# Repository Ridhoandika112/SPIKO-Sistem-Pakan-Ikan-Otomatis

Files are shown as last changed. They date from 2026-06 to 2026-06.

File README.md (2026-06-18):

#  Sistem Pakan Ikan Otomatis Di Aquarium Berbasis IoT


# Deskripsi Proyek
Proyek ini memanfaatkan mikrokontroler Arduino Mega (ATMega2560) sebagai platform utama, yang terintegrasi dengan beberapa sensor dan aktuator, yaitu sensor suhu air DS18B20, sensor pH, motor servo sebagai mekanisme pembuka pakan, serta modul RTC DS3231 untuk pengaturan dan penjadwalan waktu yang presisi. Sistem ini bertujuan untuk mengotomatisasi proses pemberian pakan ikan sesuai jadwal yang telah ditentukan. Data parameter kualitas air (suhu dan pH) akan dikirimkan secara kontinu ke sebuah dashboard web yang dapat diakses dari jarak jauh melalui internet. Selain fitur otomatisasi, sistem juga menyediakan fasilitas kontrol manual melalui aplikasi mobile atau web, sehingga pengguna tetap dapat mengintervensi pemberian pakan secara langsung sesuai kebutuhan.

---

# Tujuan Proyek
Membangun sistem otomatisasi pemberian pakan ikan berbasis mikrokontroler Arduino Mega yang dapat bekerja secara terjadwal, memantau kualitas air secara real-time, serta memungkinkan pengendalian dan pemantauan jarak jauh melalui dashboard web.

---
## Support By

> * Dosen Pengampu: Akhmad Hendriawan ST., MT. (NIP. 197501272002121003)
> * Mata Kuliah: Mikrokontroller
> * Program Studi: D4 Teknik Elektronika 
> * Politeknik Elektronika Negeri Surabaya

#  Anggota Tim


| NRP | Nama | Jobdesk | Akun |
|-----|---|---|---|
| 2124600031 | Aidan Pasha Rabani | Project Manager | [Aidan031](https://github.com/Aidan031) |
| 2124600034 | M Arya Cendekia S| Hardware Specialist | [maryacs212434](https://github.com/maryacs212434) |
| 2124600058 | M Reihan Maulana | Programmer | [reiihaaannn](https://github.com/reiihaaannn) |
| 2124600043 | Sabrina Keisha Maharani | UI/UX Designer | [sabrinakeisha](https://github.com/sabrinakeisha) |
| 2124600051 | M Ridho Andika | 3D Designer | [Ridhoandika112](https://github.com/Ridhoandika112) |
| 2124600035 | Setyo Wahyu Nur F | Hardware Specialist |[bopengfirmansyah-sketch](https://github.com/bopengfirmansyah-sketch)|

---

### Fitur Utama

| Fitur | Kegunaan |
| :---: | :---: |
|**IoT Web Dashboard** | Antarmuka pengguna responsif untuk pemantauan kualitas air dan status perangkat secara *real-time*. |
|**Penjadwalan Presisi** | Pemberian pakan otomatis yang diatur secara presisi menggunakan modul RTC DS3231. |
|**Sensor Suhu DS18B20** | Pembacaan suhu air kolam secara akurat (protokol *One-Wire*) untuk memantau kelayakan habitat. |
|**Sensor pH Analog** | Deteksi tingkat keasaman atau kebasaan air secara berkesinambungan untuk mencegah anomali. |
|**Dual Control Mode** | Mendukung eksekusi pemberian pakan secara otomatis sesuai jadwal maupun *override* kontrol manual. |
|**Arduino Mega 2560** | Pusat komputasi sistem yang tangguh dengan kapasitas I/O berlimpah untuk kelancaran multi-sensor. |
|**Aktuator Presisi** | Menggunakan Motor Servo untuk mekanisme katup pakan dengan pengaturan porsi (Kecil, Sedang, Besar). |

---

### Daftar Komponen & Spesifikasi Perangkat Keras

| Komponen | Spesifikasi / Konfigurasi Pin | Fungsi Utama pada Sistem |
| :---: | :---: | :---: |
|**Arduino Mega 2560** | ATmega2560, 5V, 16 MHz | Mikrokontroler utama sebagai pusat pemrosesan logika kontrol, pembacaan data sensor, dan eksekusi aktuator. |
| **Motor Servo** | *PWM Output* (Pin Digital 9) | Bertindak sebagai mekanik pembuka dan penutup katup wadah pakan sesuai porsi/durasi yang diinstruksikan. |
|**Modul RTC (Real-Time Clock)** | DS1307 / DS3231 (I²C: SDA Pin 20, SCL Pin 21) | Menyediakan data waktu nyata (jam, kalender) yang presisi agar jadwal pakan otomatis tidak terpengaruh saat sistem *restart*. |
| **Sensor Suhu DS18B20** | *One-Wire Digital* (Pin Digital 10) | Memantau perubahan suhu air kolam secara presisi dan mengirimkan data secara digital ke mikrokontroler. |
|**Sensor pH Air** | *Analog Input* (Pin Analog A0) | Mendeteksi tingkat keasaman/kebasaan air. *(Catatan: Pada diagram simulasi, modul ini diwakili oleh komponen Potensiometer)*. |

---

## PPT ##
<a href="https://canva.link/strf7c127qnlvye" target="_blank">
  
</a>

## Blok Diagram ##


## 3D DESIGN ##
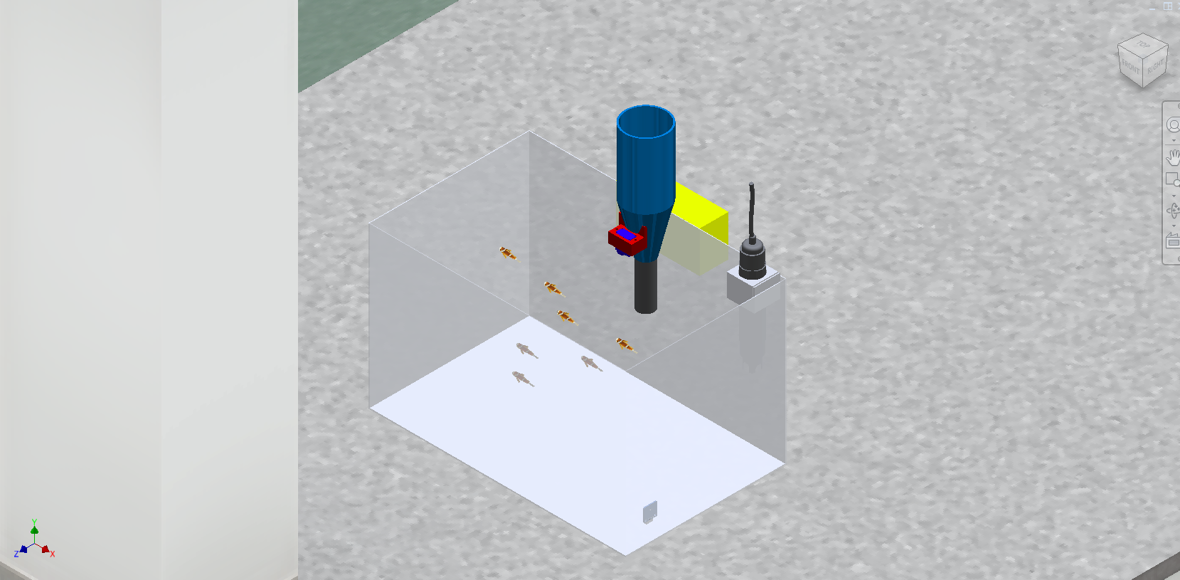
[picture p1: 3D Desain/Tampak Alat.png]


## Schematic ##
Schematic Hardware

## Board Layout ##
Board Layout

## 3D DESIGN PCB ##
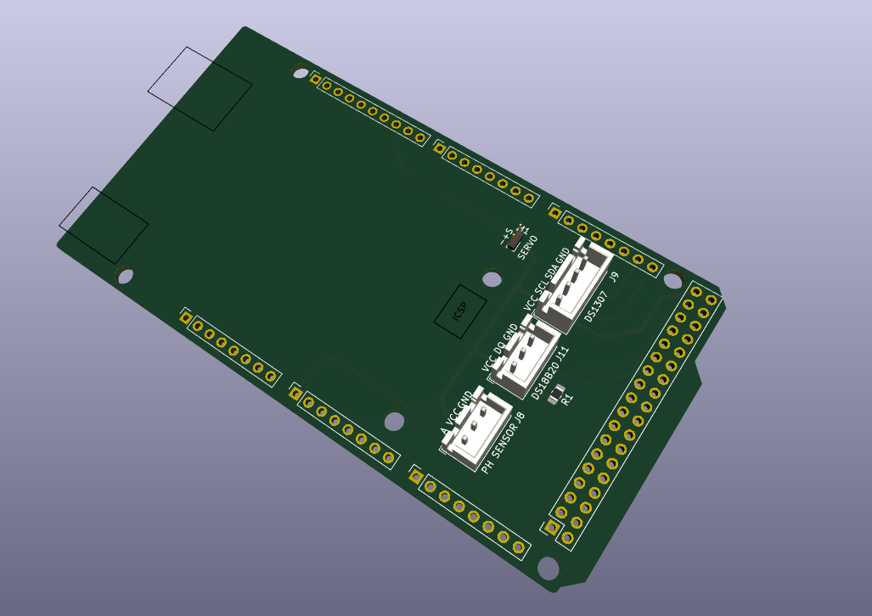
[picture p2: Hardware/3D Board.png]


## UI-UX ##
<a href="https://www.figma.com/make/QbkKy7pj1Dl7t2FqqGLqkM/Automated-Fish-Feeding-System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" target="_blank">
  
</a>

## SIMULASI WOKWI ##
<a href="https://wokwi.com/projects/465644996192840705" target="_blank">
  
</a>

## MINDMAP ##
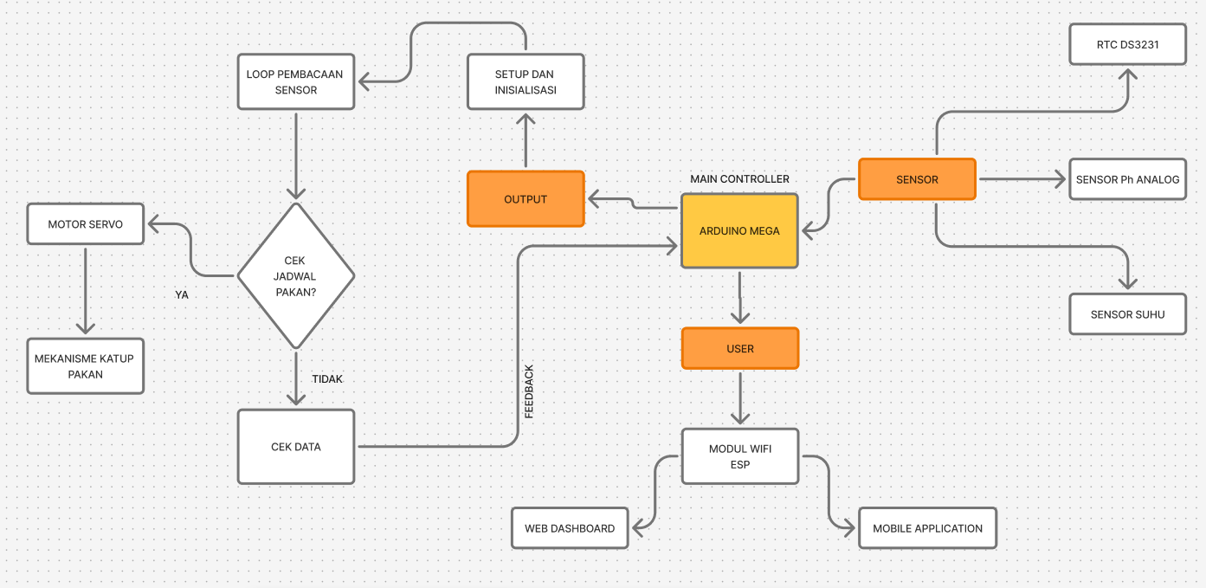
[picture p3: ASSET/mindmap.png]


## FISHBONE ##
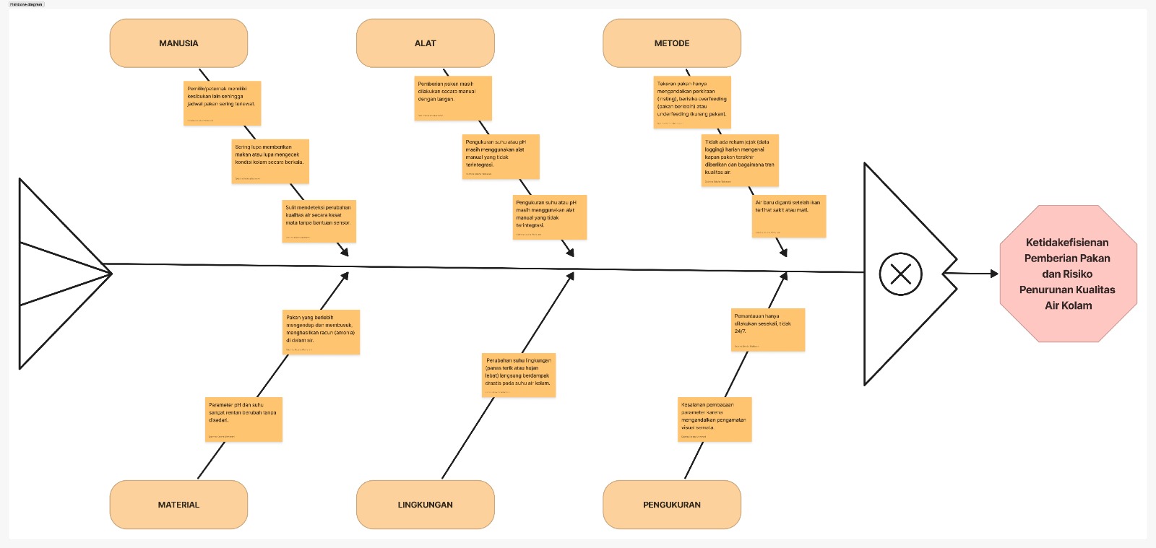
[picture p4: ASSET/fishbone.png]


## VIDIO IKLAN ##
<a href="https://github.com/Ridhoandika112/SPIKO-Sistem-Pakan-Ikan-Otomatis/blob/9bb35ed6f565db23a5436418f983b1fbc057d9f7/ASSET/vidio%20iklan%20github.mp4" target="_blank">
  
</a>

## VIDIO DEMO KESELURUHAN ##
<a href="https://drive.google.com/drive/folders/1Q5b7-XY5ffCqigkS9h1ZKFEJzIavjvMV" target="_blank">
  
</a>

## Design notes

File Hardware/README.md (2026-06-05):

##  Komponen Hardware SPIKO

Sistem **SPIKO** menggunakan beberapa komponen utama yang saling terintegrasi untuk melakukan monitoring kualitas air dan pemberian pakan secara otomatis. Mikrokontroler utama yang digunakan adalah **Arduino Mega 2560**, dengan sensor suhu, sensor pH, RTC, dan motor servo sebagai aktuator.

### Daftar Komponen

| No | Komponen | Fungsi |
| -- | --- | --- |
| 1  | **Arduino Mega 2560** | Mikrokontroler utama untuk memproses data sensor dan mengendalikan aktuator |
| 2  | **DS18B20** | Sensor suhu air |
| 3  | **DS1307 RTC Module** | Modul waktu nyata untuk penjadwalan pemberian pakan |
| 4  | **Analog pH Meter Module** | Sensor monitoring pH air |
| 5  | **Potensiometer** | Pengganti sensor pH pada simulasi |
| 6  | **Motor Servo** | Aktuator untuk membuka dan menutup wadah pakan |

---

##  Mapping Pinout ATmega2560

Berikut adalah konfigurasi pin yang digunakan pada sistem SPIKO:

| Pin Arduino Mega 2560 | Port ATmega2560 | Terhubung ke | Keterangan |
| --- | --- | --- | --- |
| **A0** | **PF0** | SIG Sensor pH / Potensiometer | Input analog untuk membaca nilai pH air |
| **22** | **PA0** | DQ Sensor DS18B20 | Jalur data sensor suhu air |
| **20** | **PD1** | SDA Modul RTC DS1307 | Jalur data komunikasi I2C |
| **21** | **PD0** | SCL Modul RTC DS1307 | Jalur clock komunikasi I2C |
| **9** | **PH6** | PWM Motor Servo | Sinyal PWM untuk mengatur gerakan servo |

---

##  Koneksi Hardware

###  Sensor Suhu DS18B20

Sensor DS18B20 digunakan untuk membaca suhu air secara digital. Pin **DQ** sensor dihubungkan ke pin **22 (PA0)** pada Arduino Mega 2560.

```text
DS18B20 DQ  → Arduino Mega Pin 22 (PA0)
VCC         → 5V
GND         → GND
```

---

### Sensor pH / Potensiometer

Pada simulasi, sensor pH digantikan menggunakan potensiometer. Output potensiometer dihubungkan ke pin analog **A0 (PF0)**.

```text
SIG Sensor pH / Potensiometer → Arduino Mega Pin A0 (PF0)
VCC                            → 5V
GND                            → GND
```

---

###  Modul RTC DS1307

Modul RTC DS1307 digunakan untuk menyimpan dan membaca waktu secara real-time. Komunikasi dilakukan menggunakan protokol **I2C**.

```text
SDA RTC DS1307 → Arduino Mega Pin 20 (PD1)
SCL RTC DS1307 → Arduino Mega Pin 21 (PD0)
VCC            → 5V
GND            → GND
```

---

### Motor Servo

Motor servo digunakan sebagai aktuator untuk membuka dan menutup mekanisme pemberian pakan. Sinyal kontrol servo diberikan melalui pin **9 (PH6)**.

```text
Signal Servo → Arduino Mega Pin 9 (PH6)
VCC          → 5V
GND          → GND
```

---

## Ringkasan Sistem

Sistem SPIKO bekerja dengan membaca parameter suhu dan pH air, kemudian menggunakan modul RTC DS1307 sebagai acuan waktu untuk proses pemberian pakan otomatis. Data dari sensor diproses oleh Arduino Mega 2560, sedangkan motor servo berfungsi sebagai aktuator untuk membuka dan menutup tempat pakan sesuai jadwal yang telah ditentukan.

Dengan konfigurasi ini, sistem dapat digunakan sebagai dasar pengembangan **monitoring dan pemberian pakan ikan otomatis** berbasis mikrokontroler.

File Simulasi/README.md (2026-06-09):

## 🚀 Quick Link Simulasi ##

Klik tautan berikut untuk membuka dan menjalankan simulasi sistem SPIKO secara langsung di Wokwi:

🔗 **[Buka Simulasi SPIKO di Wokwi](https://wokwi.com/projects/465644996192840705)**

Atau simulasi juga dapat diakses melalui file **SPIKO.zip** yang sudah disediakan pada folder Firmware.

---

## 🖥️ Pengantar Simulasi Wokwi

Simulasi sistem **SPIKO** dibuat menggunakan platform **Wokwi** sebagai media pengujian rangkaian dan program secara virtual. Melalui simulasi ini, pengguna dapat melihat bagaimana sistem monitoring kualitas air dan pemberian pakan ikan otomatis bekerja tanpa harus langsung menggunakan perangkat keras fisik.

Pada simulasi ini, **Arduino Mega 2560** digunakan sebagai mikrokontroler utama yang mengolah data dari beberapa komponen, seperti sensor suhu **DS18B20**, modul waktu nyata **RTC DS1307**, sensor pH analog yang disimulasikan menggunakan **potensiometer**, serta **motor servo** sebagai aktuator pemberi pakan.

Dengan adanya simulasi Wokwi, proses pengujian sistem menjadi lebih mudah karena pengguna dapat memantau pembacaan sensor, menguji logika program, serta memastikan aktuator bekerja sesuai dengan kondisi yang telah ditentukan. Simulasi ini juga dapat digunakan sebagai tahap awal sebelum sistem direalisasikan dalam bentuk hardware sebenarnya.

---
## INDEKS
Simulasi sistem **SPIKO** dengan tampilan figma yang diubah menjadi tampilan html untuk melakukan simulasi menggunakan **PLATFORM.IO**

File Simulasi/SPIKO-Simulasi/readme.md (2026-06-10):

# SPIKO: Sistem Pakan Ikan Otomatis & Monitoring Kualitas Air Cerdas

SPIKO adalah sistem IoT cerdas berbasis **Arduino Mega 2560 (ATMega2560 @ 16 MHz)** yang dirancang untuk otomatisasi pemberian pakan ikan serta pemantauan kualitas air secara *real-time*. Sistem ini mengintegrasikan sensor fisik suhu (DS18B20) dan keasaman air (pH Analog) dengan kontrol aktuator servo melalui dasbor web interaktif berbasis WebSocket.

## 🛠️ Arsitektur Komunikasi Sistem
Sistem ini menggunakan arsitektur komunikasi data *full-duplex* tiga arah yang menjamin transmisi data tanpa hambatan (*non-blocking*):

1. **Lapisan Perangkat Keras (Firmware C++):**
   Arduino Mega membaca data sensor secara berkala menggunakan logika `millis()` dan mengirimkannya dalam format JSON melalui port serial `Serial1` (Pin 18/19). Lapisan ini juga mendengarkan instruksi eksekusi pakan dari web.
   
2. **Jembatan Jaringan (Node.js Bridge):**
   Aplikasi `bridge.js` bertindak sebagai *multi-protocol gateway*. Ia membuka **Raw TCP Server** di port `8080` untuk menangkap data dari simulator Wokwi, menggunakan mekanisme penampung (*Buffer*) untuk mencegah fragmentasi data JSON, kemudian meneruskannya melalui **WebSocket Server** di port `8081` menuju browser.

3. **Antarmuka Pengguna (Frontend Web):**
   Dasbor berbasis HTML, Tailwind CSS, dan Chart.js yang terhubung langsung ke WebSocket port `8081`. Berguna untuk visualisasi grafik tren kualitas air dan memicu intervensi pakan manual secara instan.

---

## 📌 Spesifikasi Pemetaan Pin Hardware (Wiring Map)
Berdasarkan konfigurasi pada proyek, berikut adalah pemetaan pin aktual pada Arduino Mega 2560:

| Komponen Perangkat Keras | Jenis Pin | Pin Arduino Mega | Deskripsi Fungsi |
| :--- | :--- | :--- | :--- |
| **Wokwi Serial Bridge** | Serial Async | `Pin 18 (TX1)` | Mengirimkan data JSON sensor ke RX Jembatan TCP |
| **Wokwi Serial Bridge** | Serial Async | `Pin 19 (RX1)` | Menerima perintah (`FEED_MANUAL`) dari TX Jembatan |
| **Servo Motor Pakan** | PWM Digital | `Pin 9` | Mengendalikan katup pembuka pakan (0° - 90°) |
| **Sensor Suhu DS18B20** | OneWire | `Pin 10` | Mengirim data suhu air dengan protokol 1-Wire |
| **Sensor pH Analog** | Analog Input | `Pin A0` | Membaca tegangan analog linear tingkat keasaman air |
| **DS3231 RTC Module** | I2C | `SDA / SCL` | Sinkronisasi waktu aktual berbasis jam sistem (*Real-Time Clock*) |

---

## 📋 Prasyarat Sistem
Sebelum menjalankan aplikasi, pastikan lingkungan pengembangan Anda telah dilengkapi dengan alat berikut:
- **Visual Studio Code (VS Code)**
- Ekstensi **PlatformIO IDE** & **Wokwi for VS Code**
- **Node.js** (Versi 16 ke atas direkomendasikan)
- Peramban Web Modern (Google Chrome atau Microsoft Edge)

---

## 🚀 Panduan Pengoperasian Langkah Demi Langkah
### Langkah 1: Kompilasi Firmware Perangkat Keras (PlatformIO)
1. Buka folder proyek utama Anda menggunakan VS Code.
2. Pastikan konfigurasi dependensi pada file `platformio.ini` sudah lengkap seperti berikut:
   ```ini
   [env:megaatmega2560]
   platform = atmelavr
   board = megaatmega2560
   framework = arduino
   lib_deps =
       arduino-libraries/Servo @ ^1.2.1
       SPI
       Wire
       adafruit/Adafruit BusIO @ ^1.16.1
       milesburton/DallasTemperature @ ^3.11.0
       paulstoffregen/OneWire @ ^2.3.7
       adafruit/RTClib @ ^2.1.1
3. Tekan tombol PlatformIO: Clean pada Project Tasks untuk membersihkan sisa cache kompilasi lama yang mungkin korup.
4. Klik tombol PlatformIO: Build (ikon centang di status bar bawah VS Code) untuk mengompilasi kode biner firmware.hex. Pastikan proses berakhir dengan status SUCCESS.

└── index.html            # Dasbor Pemantauan Web Interaktif (Tailwind CSS)
### Langkah 2: Eksekusi Jembatan Gateway (Node.js)
1. Buka terminal baru terintegrasi di dalam VS Code Anda.
2. Jalankan skrip jembatan komunikasi dengan mengetik perintah berikut:
   
node bridge.js

3. Pastikan terminal memunculkan log inisialisasi:
[*] SISTEM SIAP: Menunggu Wokwi di port 8080 & Web di port 8081
(Biarkan jendela terminal ini tetap terbuka dan menyala selama sistem beroperasi).

### Langkah 3: Menjalankan Simulasi Perangkat Keras (Wokwi)
1. Buka file konfigurasi tata letak perangkat keras diagram.json.
2. Klik tombol Start Simulation (ikon Play berwarna hijau) yang muncul di area editor visual Wokwi VS Code.
3. Periksa kembali terminal bridge.js yang Anda jalankan pada Langkah 2. Jika koneksi berhasil, akan muncul pesan jabat tangan (handshake):
[*] BERHASIL: Wokwi VS Code Terhubung!

### Langkah 4: Membuka Dasbor Monitoring (Frontend Web)
1. Cari file index.html di dalam direktori proyek Anda.
2. Buka file index.html tersebut dengan klik ganda atau klik kanan dan pilih peramban web pilihan Anda (Google Chrome atau Microsoft Edge sangat direkomendasikan).
3. Dasbor akan langsung terhubung secara otomatis ke gerbang port 8081 melalui protokol WebSocket.
4. Indikator pada sidebar kiri yang semula merah bertuliskan "Bridge Offline" akan seketika berubah menjadi hijau bertuliskan "Arduino Terhubung", menandakan visualisasi grafik dan kontrol pakan manual siap digunakan.

## Struktur Directory Project Pada Platform.Io
 ```
SPIKO-Project/
├── .pio/                 # Berisi cache kompilasi PlatformIO (Abaikan)
├── include/              # Folder untuk file header tambahan (.h)
├── src/
│   └── main.cpp          # Firmware Utama C++ (Logika Arduino Mega)
├── diagram.json          # Konfigurasi Pinout & Kabel Simulator Wokwi
├── platformio.ini        # Manajer Dependensi Library PlatformIO
├── bridge.js             # Gateway Server TCP-to-WebSocket (Node.js)
└── index.html            # Dasbor Pemantauan Web Interaktif (Tailwind CSS)
 ```

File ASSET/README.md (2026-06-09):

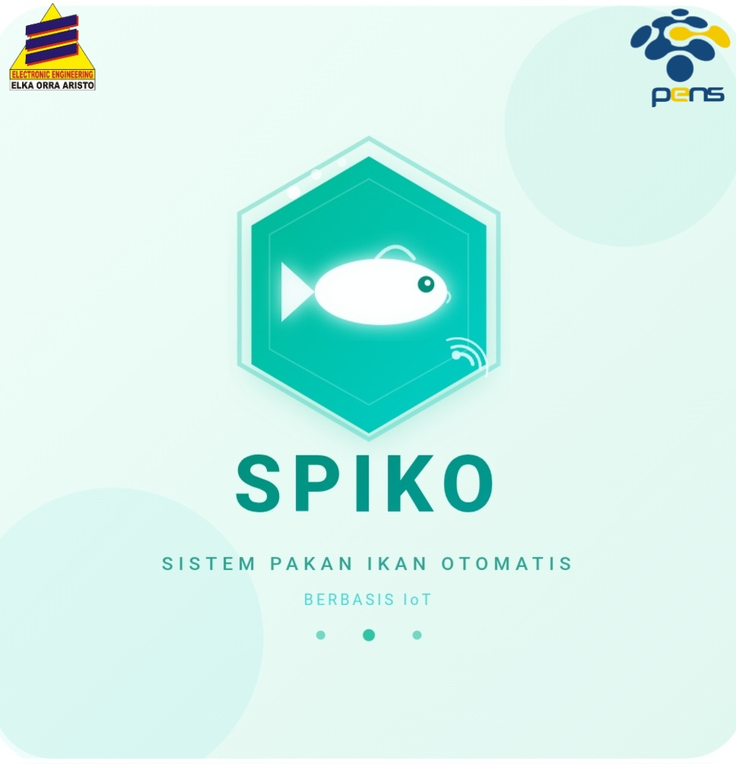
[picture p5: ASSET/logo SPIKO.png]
image_alt

SPIKO (Sistem Pakan Ikan Otomatis Berbasis IoT) Secara visual, penggabungan seluruh elemen dalam logo ini tidak hanya sekadar estetika, melainkan sebuah representasi dari "Smart Aquaculture". Bentuk ikan yang berada di dalam bingkai hexagonal dengan pancaran sinyal menegaskan posisi SPIKO sebagai wadah pelindung sekaligus pendorong modernisasi perikanan. SPIKO merepresentasikan perpaduan antara teknologi modern dan sektor perikanan untuk menciptakan solusi budidaya yang lebih efisien, cerdas, dan berkelanjutan.
Makna dalam logo: 

1. Bentuk ikan pada pusat logo melambangkan fokus utama SPIKO, yaitu membantu para pembudidaya dalam menjaga kebutuhan nutrisi ikan secara tepat dan terjadwal. Ikon ikan juga menggambarkan komitmen SPIKO dalam mendukung peningkatan produktivitas dan kesejahteraan sektor perikanan.

2. Simbol gelombang sinyal menunjukkan penerapan teknologi Internet of Things (IoT) yang memungkinkan proses monitoring dan kontrol dilakukan secara real-time. Elemen ini mencerminkan inovasi, konektivitas, dan kemudahan akses yang menjadi nilai utama SPIKO dalam era digital.

3. Bingkai hexagonal (segi enam) melambangkan stabilitas, efisiensi, dan integrasi teknologi. Bentuk ini merepresentasikan sistem yang kokoh, terstruktur, dan mampu menghubungkan berbagai komponen menjadi satu solusi yang andal.

4. Penggunaan warna toska mencerminkan keseimbangan antara teknologi dan lingkungan. Warna ini melambangkan pertumbuhan, keberlanjutan, inovasi, serta harapan untuk menciptakan budidaya perikanan yang lebih modern dan ramah lingkungan.

Secara keseluruhan, logo SPIKO menggambarkan identitas sebuah produk teknologi yang cerdas, inovatif, dan terpercaya, yang hadir untuk membantu pembudidaya ikan mengoptimalkan proses pemberian pakan melalui sistem otomatis berbasis IoT.

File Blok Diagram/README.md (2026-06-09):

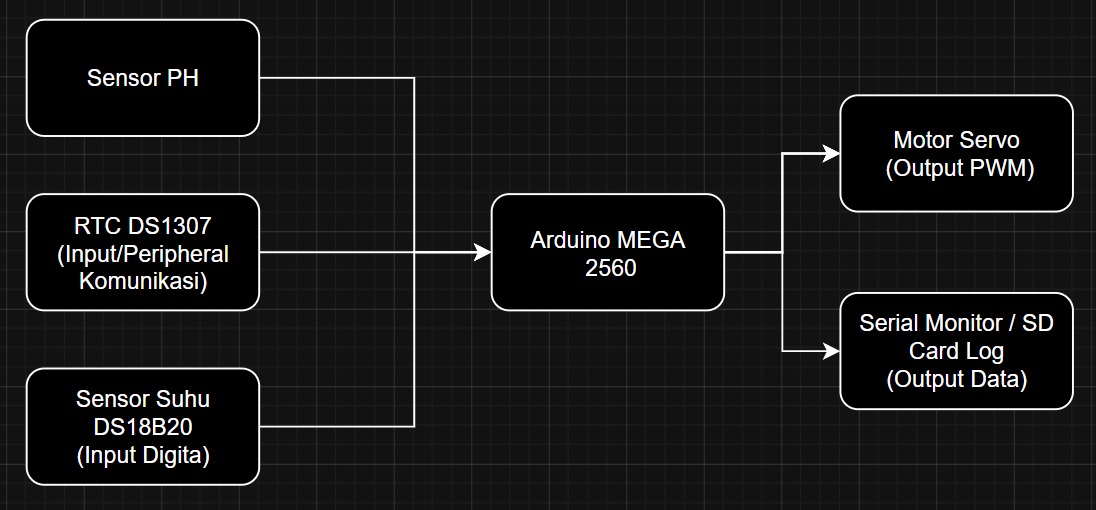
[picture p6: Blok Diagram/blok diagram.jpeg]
image_alt


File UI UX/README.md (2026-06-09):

# TAMPILAN APLIKASI
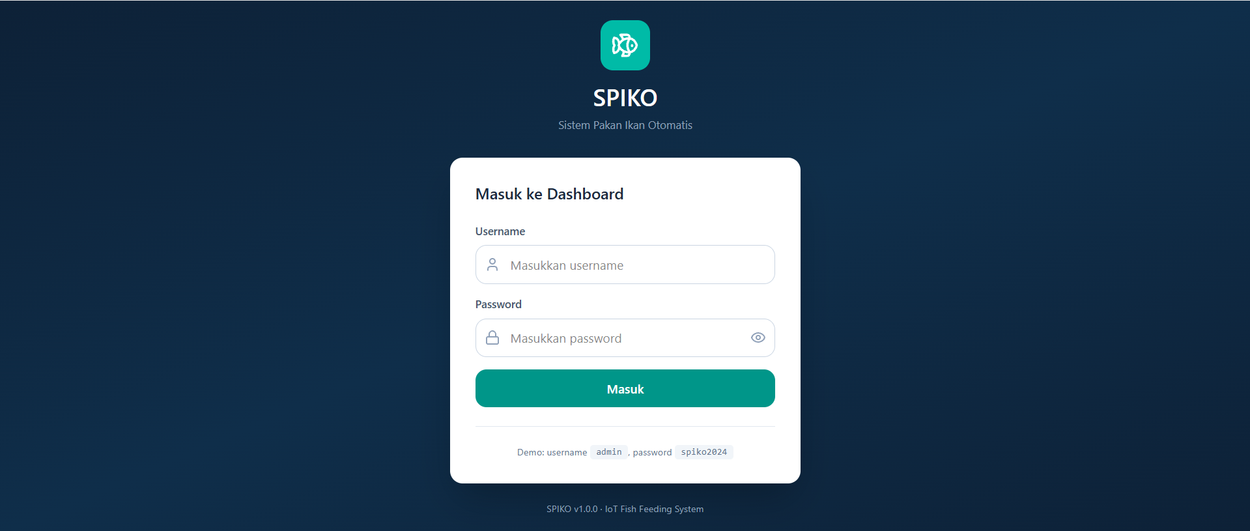
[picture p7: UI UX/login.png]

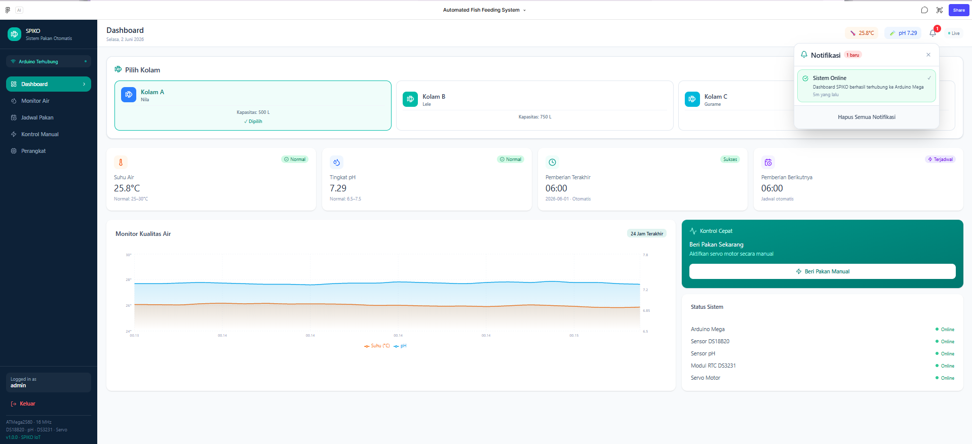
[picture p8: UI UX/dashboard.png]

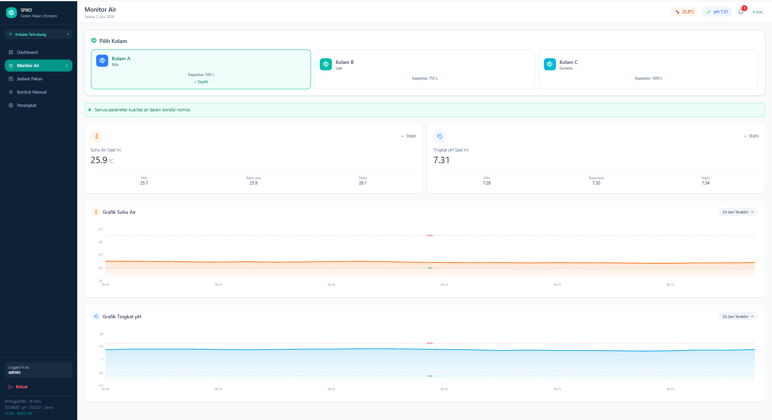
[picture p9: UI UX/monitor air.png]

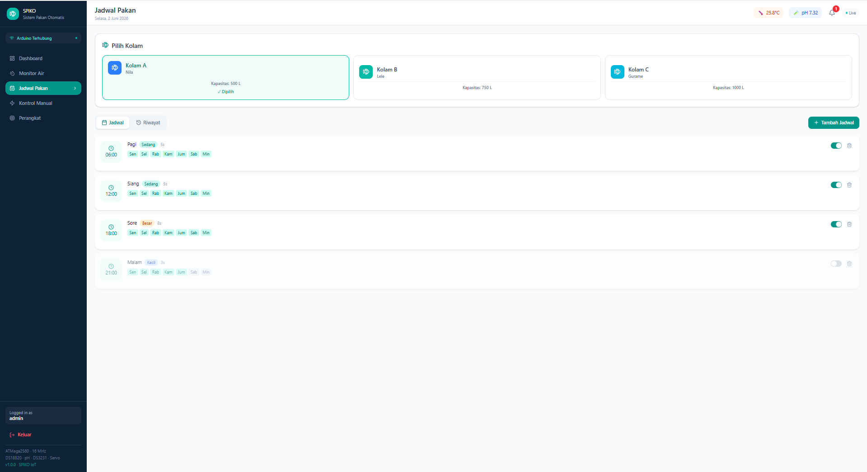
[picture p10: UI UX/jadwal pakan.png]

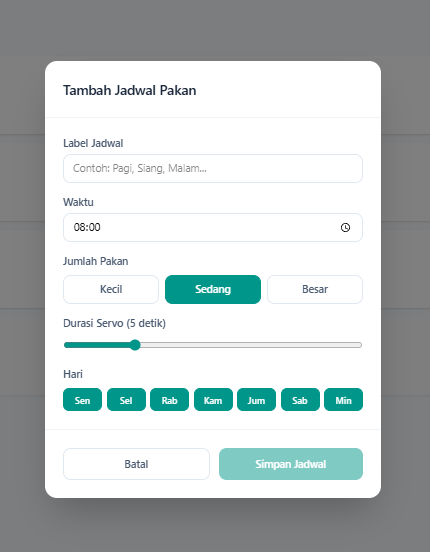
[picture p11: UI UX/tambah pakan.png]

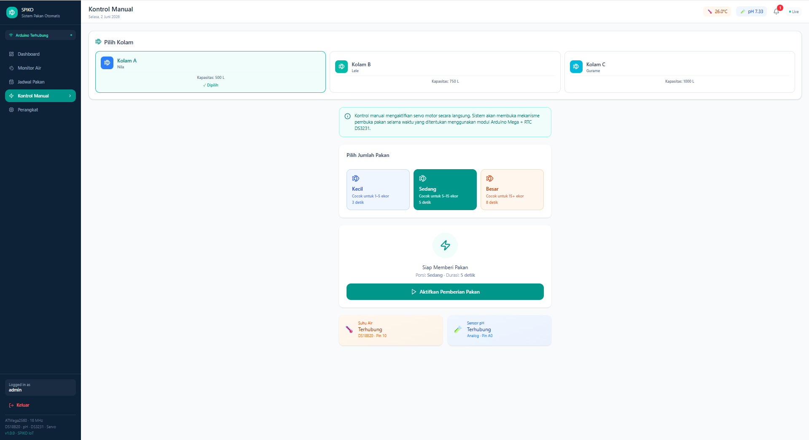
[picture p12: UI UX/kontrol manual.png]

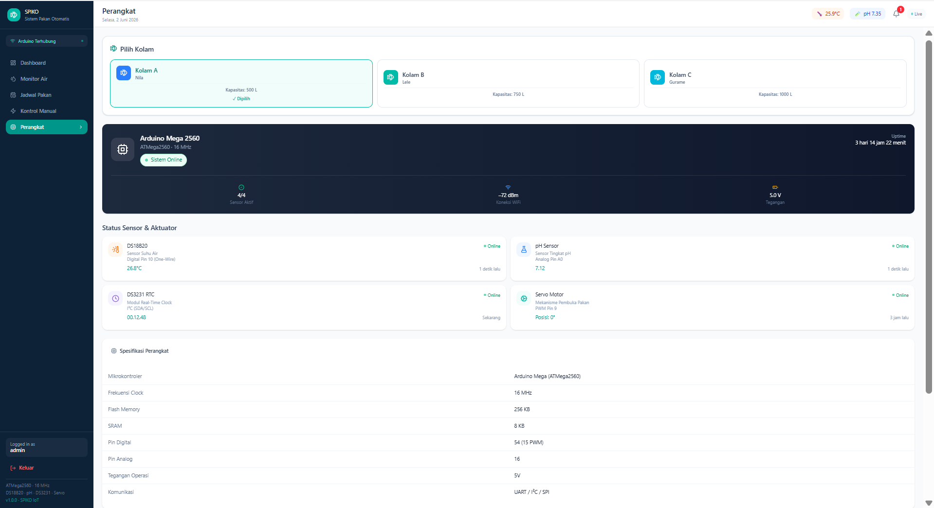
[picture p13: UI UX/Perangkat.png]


# LINK UI/UX
<a href="https://www.figma.com/make/QbkKy7pj1Dl7t2FqqGLqkM/Automated-Fish-Feeding-System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" target="_blank">
  
</a>

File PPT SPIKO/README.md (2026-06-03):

# SLIDE SHOW PPT
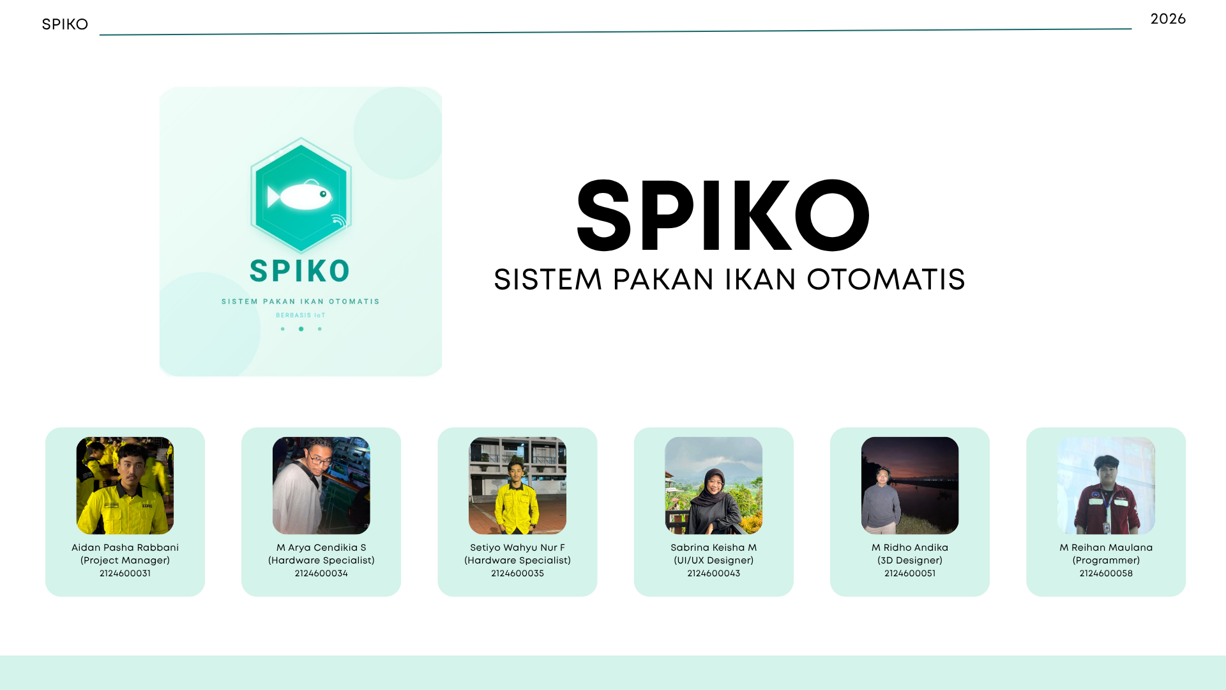
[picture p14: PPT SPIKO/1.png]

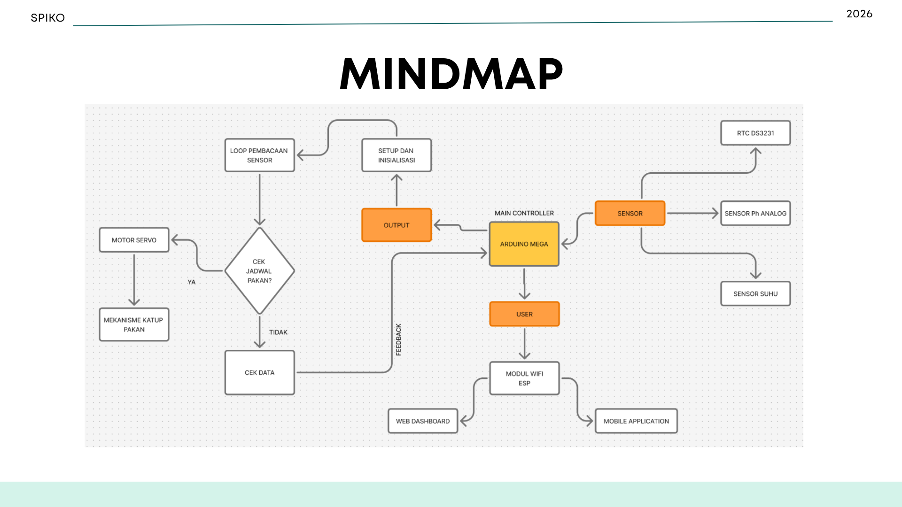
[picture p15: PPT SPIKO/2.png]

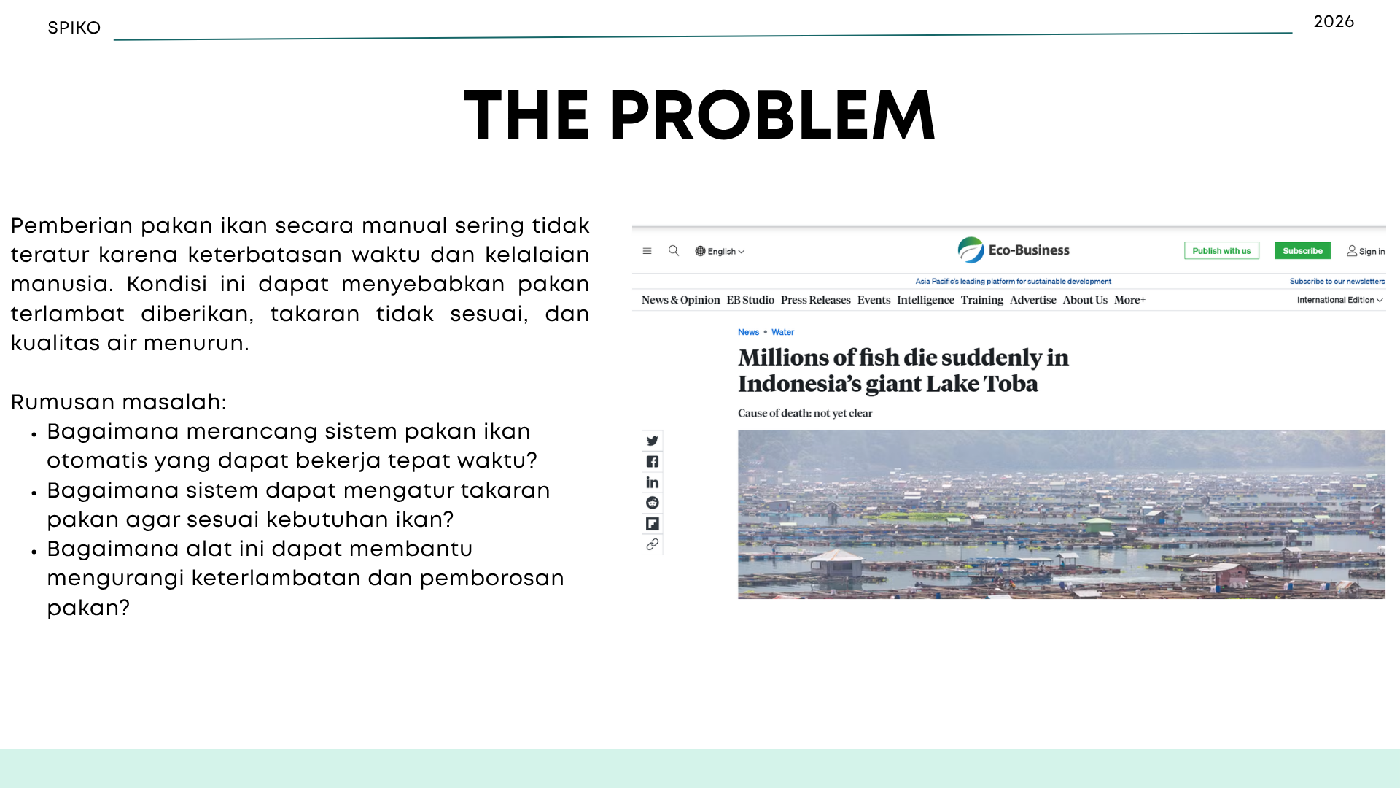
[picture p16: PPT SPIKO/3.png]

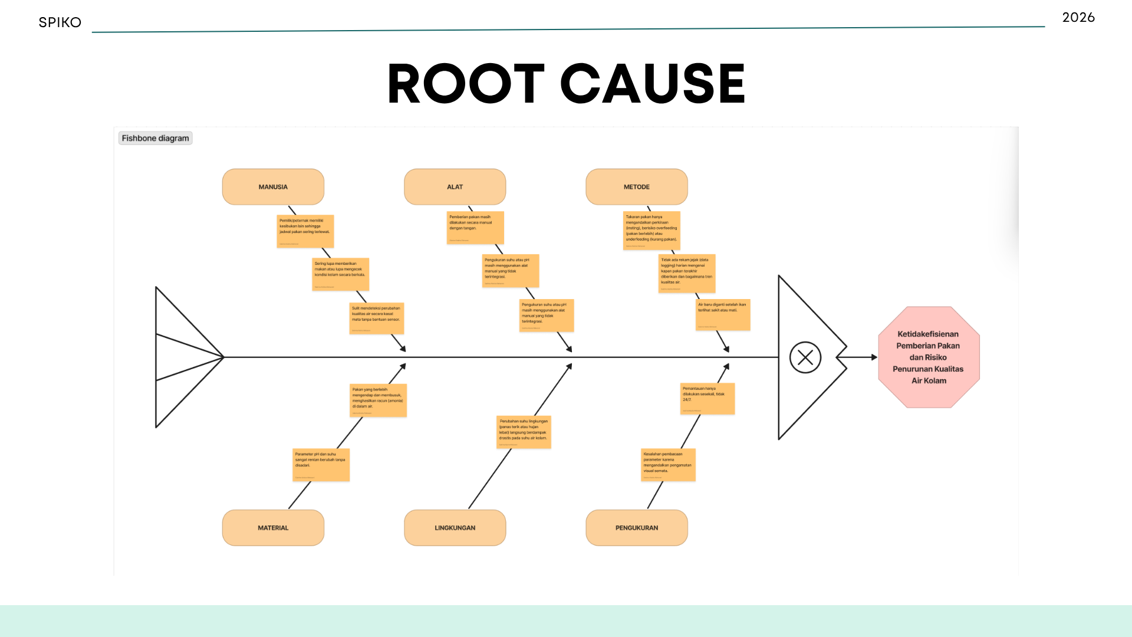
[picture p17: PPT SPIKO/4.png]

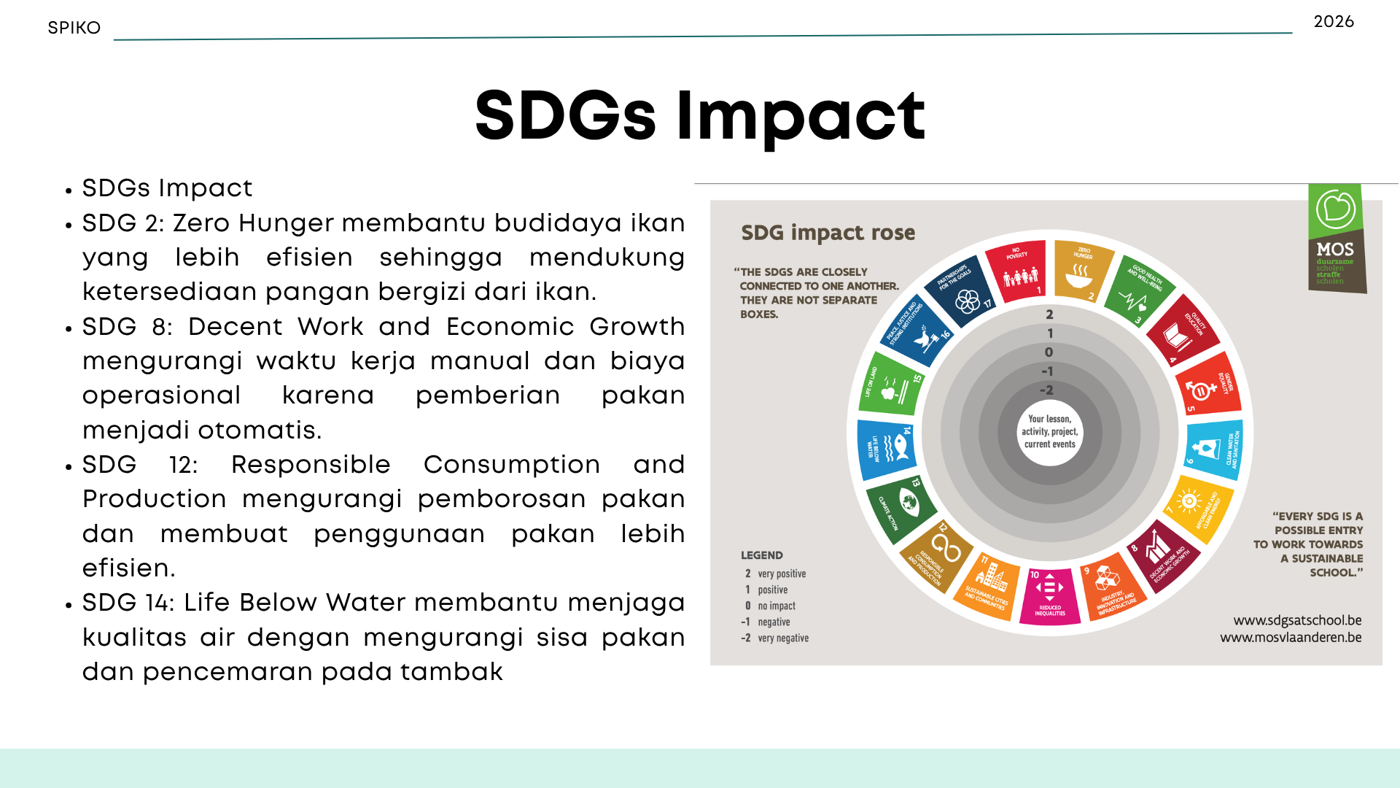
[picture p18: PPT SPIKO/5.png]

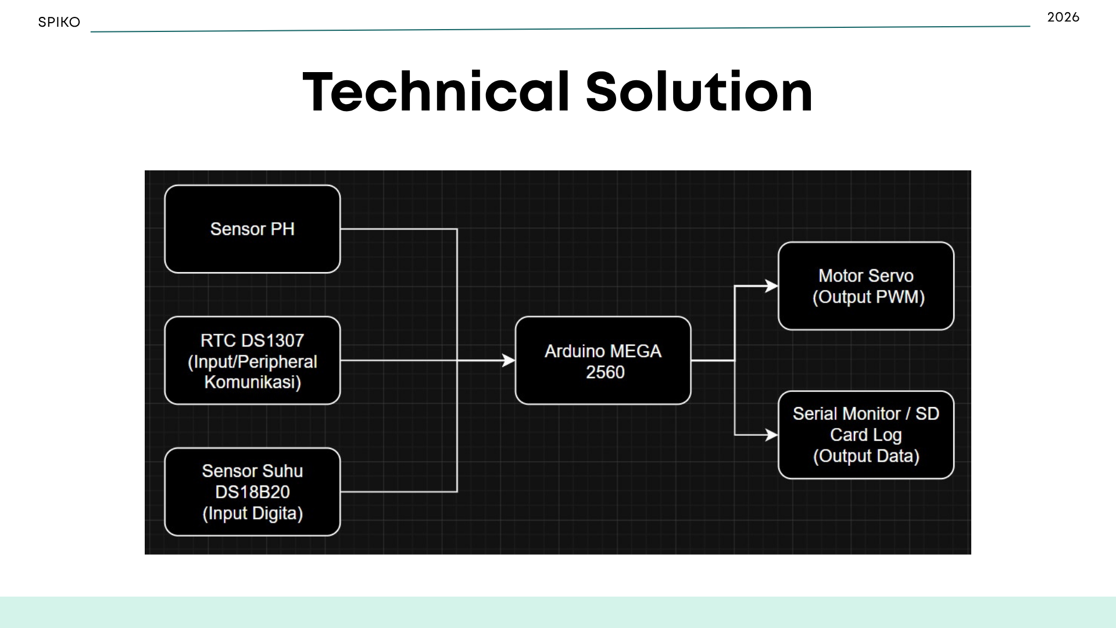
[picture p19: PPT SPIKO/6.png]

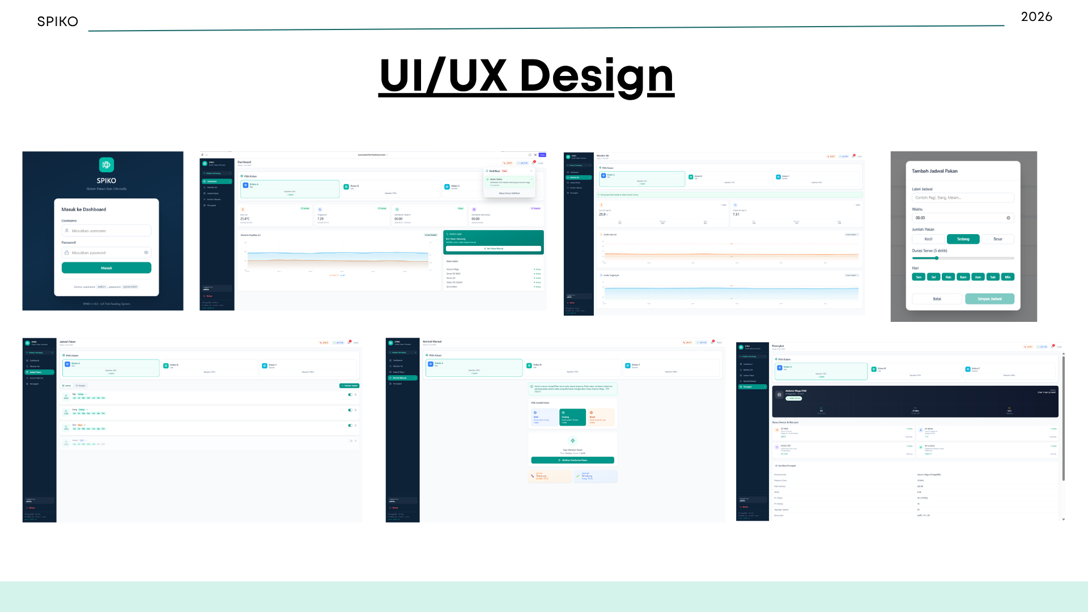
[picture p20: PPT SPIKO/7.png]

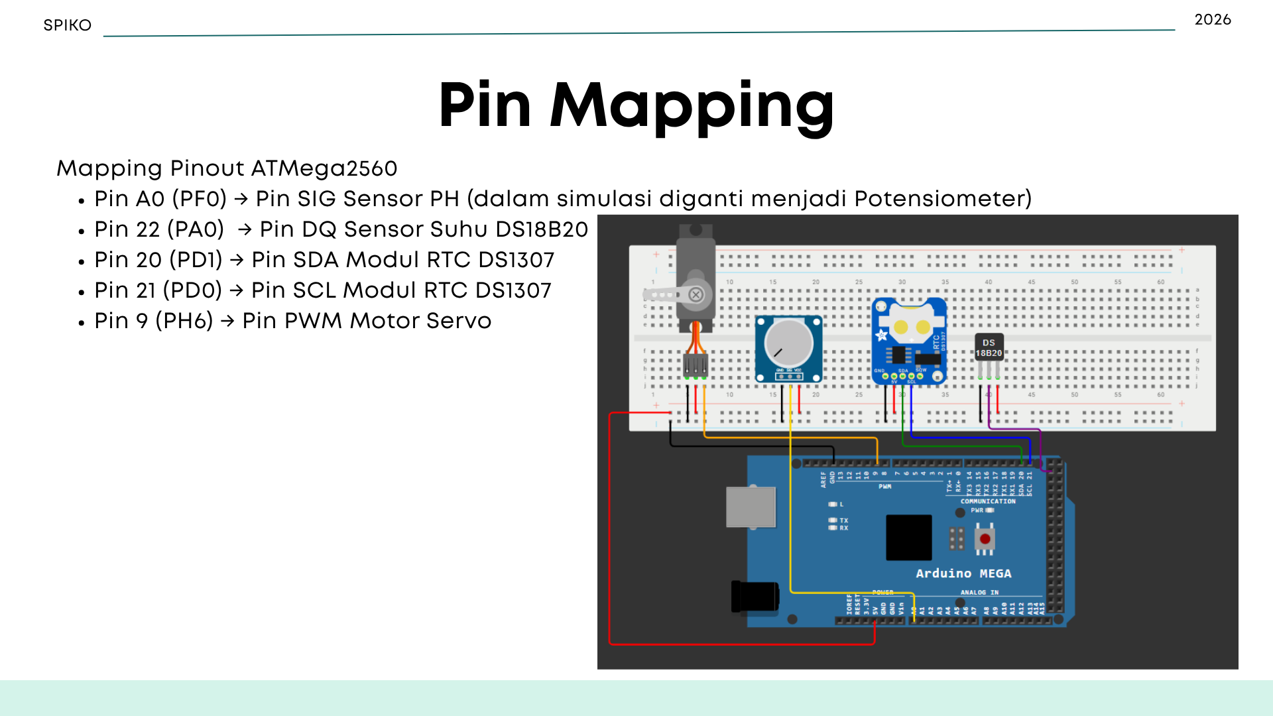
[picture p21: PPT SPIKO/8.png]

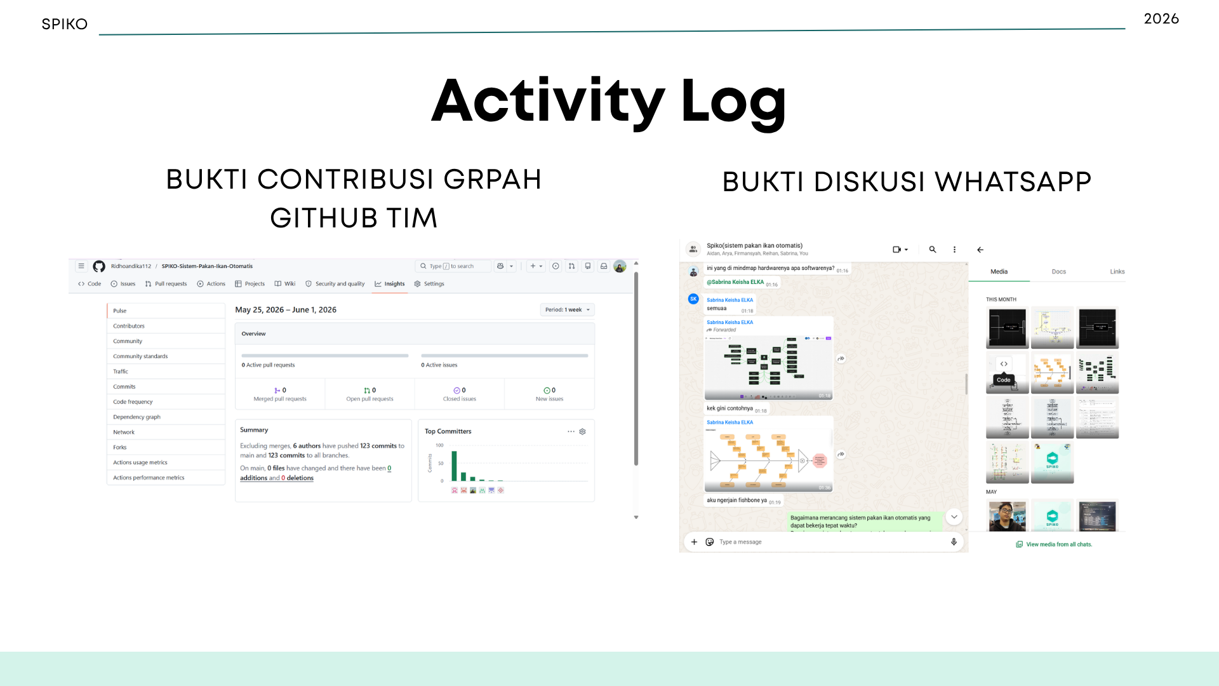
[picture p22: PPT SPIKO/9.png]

# LINK CANVA
https://canva.link/strf7c127qnlvye

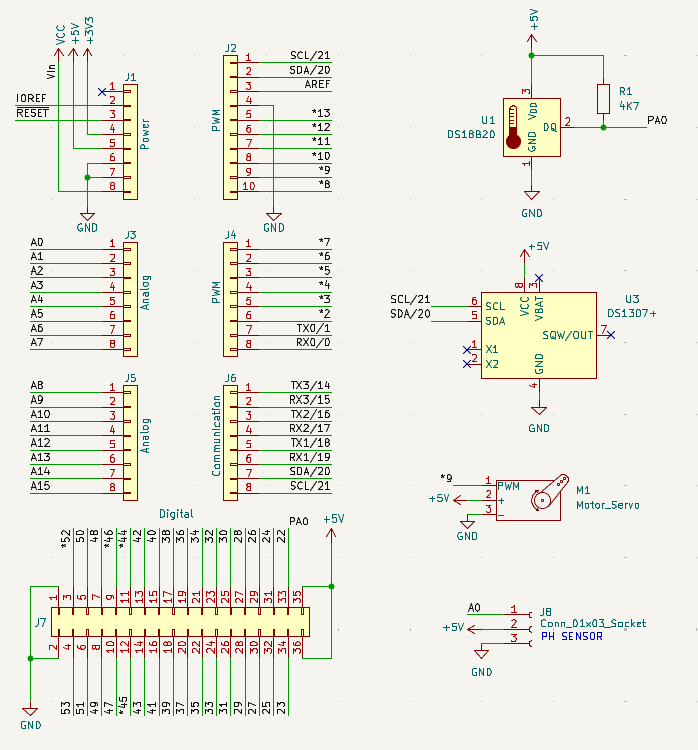
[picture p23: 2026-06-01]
Hardware/Schematic Hardware.png

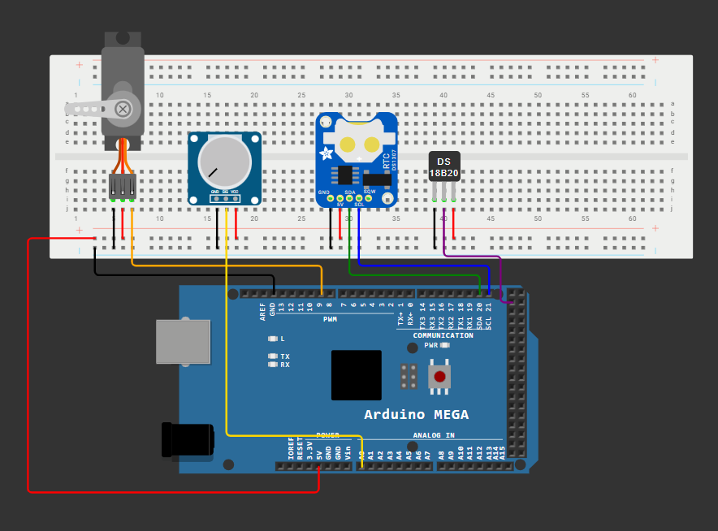
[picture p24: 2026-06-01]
Hardware/Schematic simulasi.png

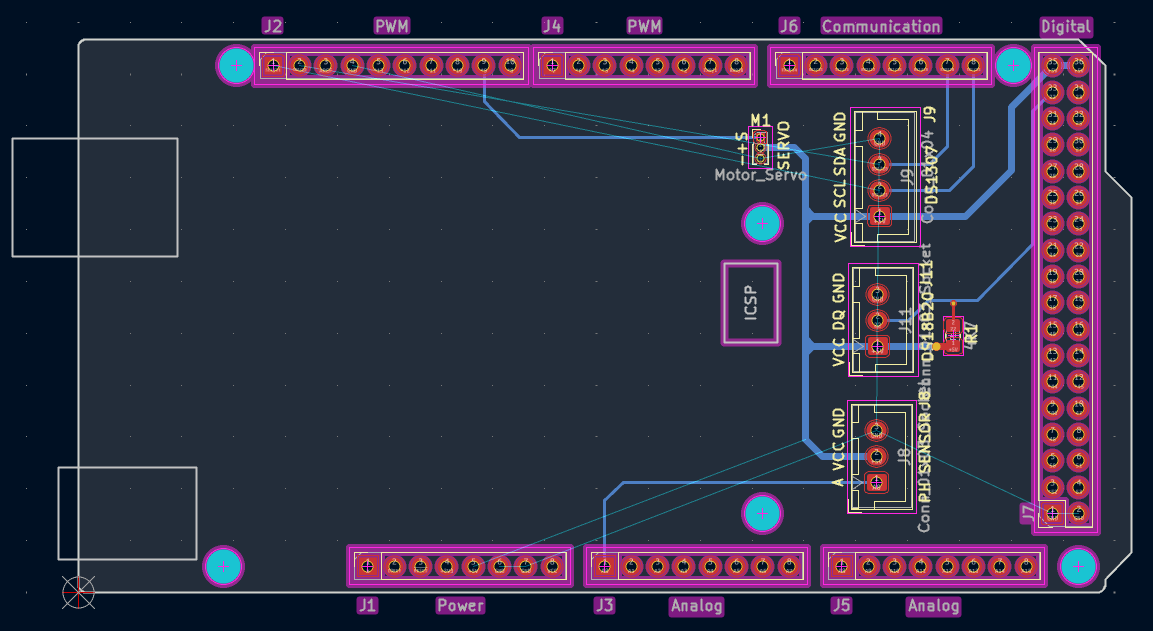
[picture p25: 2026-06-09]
Hardware/Board Layout.png

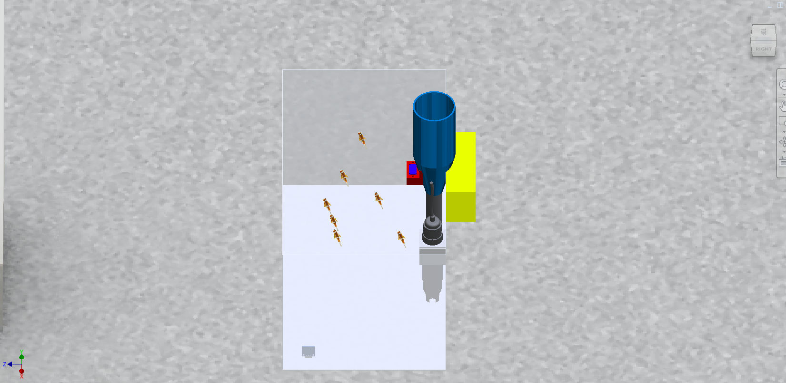
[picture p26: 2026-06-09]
3D Desain/Tampak Samping.png

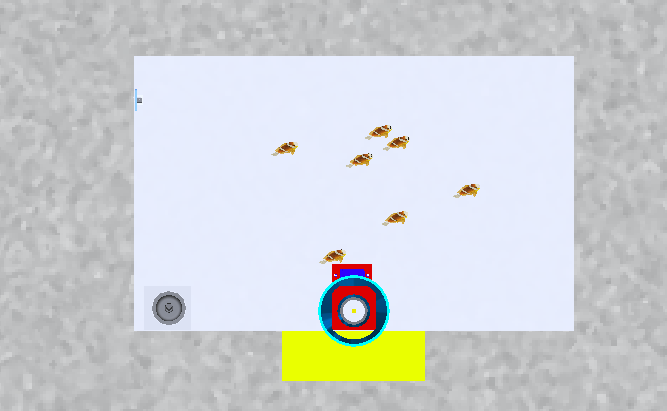
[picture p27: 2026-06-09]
3D Desain/Tampak Atas.png

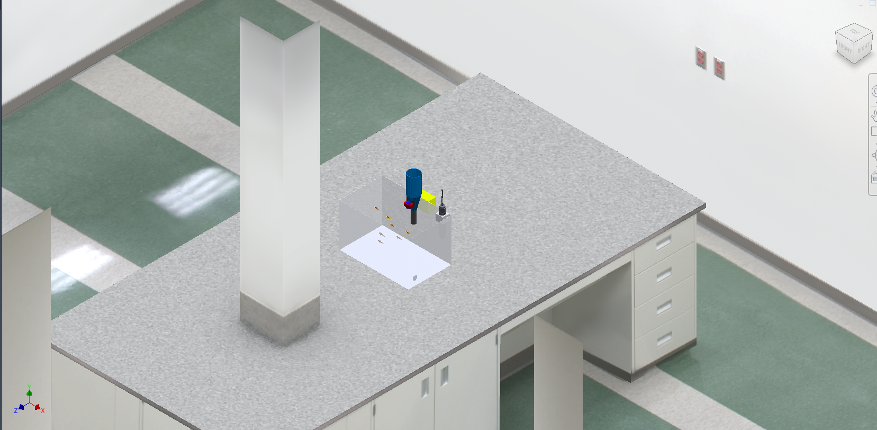
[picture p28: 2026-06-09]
3D Desain/Tampak Aquarium.png

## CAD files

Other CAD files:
3D Desain/project mikro.iam

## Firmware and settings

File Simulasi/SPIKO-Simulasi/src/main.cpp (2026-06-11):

/*
   SISTEM MONITORING DAN PEMBERI PAKAN IKAN OTOMATIS
   AVR Bare Metal - ATmega2560 / Arduino Mega 2560
*/

#define F_CPU 16000000UL

#include <avr/io.h>
#include <util/delay.h>
#include <stdint.h>
#include <stdlib.h>
#include <string.h>
#include <avr/interrupt.h> // WAJIB untuk Interupsi Serial

// =====================================================
// KONFIGURASI PIN
// =====================================================
#define DS18B20_DDR   DDRA
#define DS18B20_PORT  PORTA
#define DS18B20_PINR  PINA
#define DS18B20_PIN   PA0

#define SERVO_DDR   DDRH
#define SERVO_PORT  PORTH
#define SERVO_PIN   PH6

#define DS1307_ADDR 0x68

// =====================================================
// VARIABEL GLOBAL
// =====================================================
uint8_t jamPakan1 = 20, menitPakan1 = 34;
uint8_t jamPakan2 = 21, menitPakan2 = 0;
uint8_t sudahPakan1 = 0, sudahPakan2 = 0;

// Ring Buffer untuk Interupsi UART RX
#define RX_BUF_SIZE 64
volatile char rx_buffer[RX_BUF_SIZE];
volatile uint8_t rx_head = 0;
volatile uint8_t rx_tail = 0;

// =====================================================
// INTERUPSI SERIAL RX (Menangkap data di balik layar)
// =====================================================
ISR(USART0_RX_vect)
{
    char c = UDR0;
    uint8_t next_head = (rx_head + 1) % RX_BUF_SIZE;
    if (next_head != rx_tail)
    {
        rx_buffer[rx_head] = c;
        rx_head = next_head;
    }
}

// =====================================================
// DELAY VARIABEL
// =====================================================
void delay_ms_var(uint16_t ms) { while (ms--) { _delay_ms(1); } }
void delay_us_var(uint16_t us) { while (us--) { _delay_us(1); } }

// =====================================================
// UART0 — TX + RX
// =====================================================
void UART0_Init(uint32_t baud)
{
    uint16_t ubrr = (F_CPU / (16UL * baud)) - 1;
    UBRR0H = (uint8_t)(ubrr >> 8);
    UBRR0L = (uint8_t)ubrr;

    // Enable TX, RX, dan Interupsi RX
    UCSR0B = (1 << TXEN0) | (1 << RXEN0) | (1 << RXCIE0);
    UCSR0C = (1 << UCSZ01) | (1 << UCSZ00);

    sei(); // Aktifkan Global Interrupt
}

void UART0_SendChar(char data)
{
    while (!(UCSR0A & (1 << UDRE0)));
    UDR0 = data;
}

void UART0_SendString(const char *str)
{
    while (*str) UART0_SendChar(*str++);
}

void UART0_SendInt(int16_t data)
{
    char buffer[10];
    itoa(data, buffer, 10);
    UART0_SendString(buffer);
}

uint8_t UART0_Available(void)
{
    return (rx_head != rx_tail);
}

char UART0_ReadChar(void)
{
    if (rx_head == rx_tail) return 0;
    char c = rx_buffer[rx_tail];
    rx_tail = (rx_tail + 1) % RX_BUF_SIZE;
    return c;
}

uint8_t UART0_ReadLine(char *buf, uint8_t maxLen)
{
    static uint8_t i = 0;
    while (UART0_Available())
    {
        char c = UART0_ReadChar();
        if (c == '\n' || c == '\r')
        {
            if (i == 0) continue; // Abaikan karakter kosong berturut-turut
            buf[i] = '\0';
            i = 0;
            return 1;
        }
        else if (i < maxLen - 1)
        {
            buf[i++] = c;
        }
    }
    return 0;
}

// =====================================================
// ADC UNTUK PH SENSOR
// =====================================================
void ADC_Init(void)
{
    ADMUX  = (1 << REFS0);
    ADCSRA = (1 << ADEN) | (1 << ADPS2) | (1 << ADPS1) | (1 << ADPS0);
}

uint16_t ADC_Read(uint8_t channel)
{
    ADMUX = (ADMUX & 0xE0) | (channel & 0x1F);
    ADCSRA |= (1 << ADSC);
    while (ADCSRA & (1 << ADSC));
    return ADC;
}

float bacaPH(void)
{
    uint16_t adcValue = ADC_Read(0);
    return ((float)adcValue * 14.0) / 1023.0;
}

// =====================================================
// TWI / I2C UNTUK RTC DS1307
// =====================================================
void TWI_Init(void) { TWBR = 72; TWSR = 0x00; }
void TWI_Start(void) { TWCR = (1 << TWINT) | (1 << TWSTA) | (1 << TWEN); while (!(TWCR & (1 << TWINT))); }
void TWI_Stop(void) { TWCR = (1 << TWINT) | (1 << TWSTO) | (1 << TWEN); }
void TWI_Write(uint8_t data) { TWDR = data; TWCR = (1 << TWINT) | (1 << TWEN); while (!(TWCR & (1 << TWINT))); }
uint8_t TWI_Read_ACK(void) { TWCR = (1 << TWINT) | (1 << TWEN) | (1 << TWEA); while (!(TWCR & (1 << TWINT))); return TWDR; }
uint8_t TWI_Read_NACK(void) { TWCR = (1 << TWINT) | (1 << TWEN); while (!(TWCR & (1 << TWINT))); return TWDR; }

uint8_t bcdToDec(uint8_t val) { return ((val >> 4) * 10) + (val & 0x0F); }
uint8_t decToBcd(uint8_t val) { return ((val / 10) << 4) | (val % 10); }

void RTC_ReadTime(uint8_t *jam, uint8_t *menit, uint8_t *detik)
{
    TWI_Start();
    TWI_Write(DS1307_ADDR << 1);
    TWI_Write(0x00);
    TWI_Start();
    TWI_Write((DS1307_ADDR << 1) | 1);
    uint8_t rawDetik = TWI_Read_ACK();
    uint8_t rawMenit = TWI_Read_ACK();
    uint8_t rawJam   = TWI_Read_NACK();
    TWI_Stop();
    *detik = bcdToDec(rawDetik & 0x7F);
    *menit = bcdToDec(rawMenit);
    *jam   = bcdToDec(rawJam & 0x3F);
}

// =====================================================
// ONE WIRE UNTUK DS18B20 (Ditambahkan Proteksi CLI/SEI)
// =====================================================
void OneWire_Low(void) { DS18B20_DDR |= (1 << DS18B20_PIN); DS18B20_PORT &= ~(1 << DS18B20_PIN); }
void OneWire_Release(void) { DS18B20_DDR &= ~(1 << DS18B20_PIN); DS18B20_PORT |= (1 << DS18B20_PIN); }

uint8_t OneWire_Reset(void)
{
    uint8_t presence;
    OneWire_Low(); _delay_us(480);
    OneWire_Release(); _delay_us(70);
    presence = !(DS18B20_PINR & (1 << DS18B20_PIN));
    _delay_us(410);
    return presence;
}

void OneWire_WriteBit(uint8_t bit)
{
    cli(); // Matikan interupsi sejenak agar timing sensor tidak rusak
    if (bit) { OneWire_Low(); _delay_us(6);  OneWire_Release(); _delay_us(64); }
    else     { OneWire_Low(); _delay_us(60); OneWire_Release(); _delay_us(10); }
    sei();
}

uint8_t OneWire_ReadBit(void)
{
    uint8_t bit;
    cli();
    OneWire_Low(); _delay_us(6);
    OneWire_Release(); _delay_us(9);
    bit = (DS18B20_PINR & (1 << DS18B20_PIN)) ? 1 : 0;
    sei();
    _delay_us(55);
    return bit;
}

void OneWire_WriteByte(uint8_t data)
{
    for (uint8_t i = 0; i < 8; i++) { OneWire_WriteBit(data & 0x01); data >>= 1; }
}

uint8_t OneWire_ReadByte(void)
{
    uint8_t data = 0;
    for (uint8_t i = 0; i < 8; i++) { if (OneWire_ReadBit()) data |= (1 << i); }
    return data;
}

float DS18B20_ReadTemperature(void)
{
    uint8_t tempL, tempH;
    int16_t rawTemp;
    if (!OneWire_Reset()) return -127.0;
    OneWire_WriteByte(0xCC);
    OneWire_WriteByte(0x44);
    delay_ms_var(750);
    if (!OneWire_Reset()) return -127.0;
    OneWire_WriteByte(0xCC);
    OneWire_WriteByte(0xBE);
    tempL = OneWire_ReadByte();
    tempH = OneWire_ReadByte();
    rawTemp = (tempH << 8) | tempL;
    return (float)rawTemp / 16.0;
}

// =====================================================
// SERVO SOFTWARE PWM
// =====================================================
void Servo_Init(void)
{
    SERVO_DDR  |=  (1 << SERVO_PIN);
    SERVO_PORT &= ~(1 << SERVO_PIN);
}

void Servo_Write(uint8_t angle)
{
    uint16_t pulseWidth = 1000 + ((uint32_t)angle * 1000) / 180;
    SERVO_PORT |=  (1 << SERVO_PIN); delay_us_var(pulseWidth);
    SERVO_PORT &= ~(1 << SERVO_PIN); delay_us_var(20000 - pulseWidth);
}

void Servo_Hold(uint8_t angle, uint16_t duration_ms)
{
    uint16_t cycle = duration_ms / 20;
    for (uint16_t i = 0; i < cycle; i++) Servo_Write(angle);
}

// =====================================================
// FUNGSI BERI PAKAN (Disinkronkan dengan JSON Web)
// =====================================================
void beriPakan(void)
{
    UART0_SendString("{\"status\":\"Katup Dibuka\"}\r\n");
    Servo_Hold(90, 1500); // Bergerak ke 90°
    
    UART0_SendString("{\"status\":\"Katup Tertutup\"}\r\n");
    Servo_Hold(0,  1000); // Kembali ke 0°
}

// =====================================================
// PROSES PERINTAH
// =====================================================
void prosesPerintah(const char *cmd)
{
    if (strcmp(cmd, "PAKAN") == 0)
    {
        beriPakan();
    }
}

// =====================================================
// KIRIM DATA JSON
// =====================================================
void kirimJSON(uint8_t jam, uint8_t menit, uint8_t detik, float suhu, float ph)
{
    char buf[10];
    UART0_SendString("{");
    UART0_SendString("\"jam\":");    UART0_SendInt(jam);
    UART0_SendString(",\"menit\":"); UART0_SendInt(menit);
    UART0_SendString(",\"detik\":"); UART0_SendInt(detik);

    UART0_SendString(",\"suhu\":");
    dtostrf(suhu, 5, 2, buf);
    UART0_SendString(buf);

    UART0_SendString(",\"ph\":");
    dtostrf(ph, 4, 2, buf);
    UART0_SendString(buf);
    UART0_SendString("}\r\n");
}

// =====================================================
// MAIN PROGRAM
// =====================================================
int main(void)
{
    float suhuAir, nilaiPH;
    uint8_t jam, menit, detik;
    char cmdBuf[32];

    UART0_Init(9600);
    ADC_Init();
    TWI_Init();
    Servo_Init();

    OneWire_Release();
    Servo_Hold(0, 500);

    UART0_SendString("{\"event\":\"boot\",\"msg\":\"Sistem Monitoring Pakan Ikan\"}\r\n");

    while (1)
    {
        // Berkat Interrupt, kita bisa memproses perintah bertumpuk di sini
        while (UART0_ReadLine(cmdBuf, sizeof(cmdBuf)))
        {
            prosesPerintah(cmdBuf);
        }

        RTC_ReadTime(&jam, &menit, &detik);
        suhuAir  = DS18B20_ReadTemperature();
        nilaiPH  = bacaPH();

        kirimJSON(jam, menit, detik, suhuAir, nilaiPH);

        if (jam == jamPakan1 && menit == menitPakan1 && sudahPakan1 == 0) { beriPakan(); sudahPakan1 = 1; }
        if (jam == jamPakan2 && menit == menitPakan2 && sudahPakan2 == 0) { beriPakan(); sudahPakan2 = 1; }
        if (jam == 0 && menit == 0) { sudahPakan1 = 0; sudahPakan2 = 0; }

        delay_ms_var(1000);
    }
}

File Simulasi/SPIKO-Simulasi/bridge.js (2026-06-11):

const { SerialPort } = require('serialport');
const { ReadlineParser } = require('@serialport/parser-readline');
const WebSocket = require('ws');

const SERIAL_PORT = 'COM6';
const BAUD_RATE   = 9600;
const WS_PORT     = 8081;

const wsClients = new Set();
const wss = new WebSocket.Server({ port: 8081 });
console.log('[*] WebSocket Server berjalan di ws://127.0.0.1:8081');

wss.on('connection', (ws) => {
    console.log('[+] HTML Dashboard terhubung.');
    wsClients.add(ws);

    ws.on('message', (message) => {
        const cmd = message.toString().trim();
        console.log(`[PERINTAH WEB -> ARDUINO] ${cmd}`);
        if (port && port.isOpen) {
            port.write(cmd + '\n', (err) => {
                if (err) console.error('[!] Gagal kirim ke serial:', err.message);
            });
        } else {
            console.log('[!] Serial port belum terbuka.');
        }
    });

    ws.on('close', () => {
        wsClients.delete(ws);
        console.log('[-] HTML Dashboard terputus.');
    });
});

const port = new SerialPort({
    path: SERIAL_PORT,
    baudRate: BAUD_RATE,
    autoOpen: false
});

const parser = port.pipe(new ReadlineParser({ delimiter: '\n' }));

port.open((err) => {
    if (err) {
        console.error(`[!] Gagal buka ${SERIAL_PORT}:`, err.message);
        return;
    }
    console.log(`[+] Serial port ${SERIAL_PORT} terbuka @ ${BAUD_RATE} baud`);
});

parser.on('data', (line) => {
    line = line.trim();
    if (!line) return;
    console.log(`[WOKWI -> WEB] ${line}`);

    wsClients.forEach((ws) => {
        if (ws.readyState === WebSocket.OPEN) {
            ws.send(line);
        }
    });
});

port.on('error', (err) => console.error('[SERIAL ERROR]', err.message));
port.on('close', () => console.log('[!] Serial port tertutup.'));

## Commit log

2026-06-01 Add Schematic
2026-06-01 Rename Screenshot 2026-06-01 235005.png to Schematic Hardware
2026-06-01 Rename Screenshot 2026-06-02 001134.png to Schematic Simulasi
2026-06-01 Rename Schematic Hardware to Schematic Hardware.png
2026-06-01 Rename Schematic Simulasi to Schematic Simulasi.png
2026-06-01 Rename Screenshot 2026-06-02 022001.png to Schematic Simulasi.png
2026-06-09 Rename Screenshot 2026-06-09 161349.png to 3D BOARD
2026-06-09 Rename 3D BOARD to 3D BOARD.png
2026-06-09 Rename Screenshot 2026-06-09 161627.png to Board Layout.png
2026-06-10 Add schematic section to README
    Added schematic section with image to README.
